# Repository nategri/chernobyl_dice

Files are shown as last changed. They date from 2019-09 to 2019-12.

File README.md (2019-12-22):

# Chernobyl Dice


<p align="center"><i>In this clip the Chernobyl Dice set to continuously generate numbers in the range [1,26]. You
can check out a longer YouTube clip showing various modes of here: https://youtu.be/8uue9Aae9ss</i></p>

## Introduction

#### Description

The Chernobyl Dice is a quantum random number generator [0] that uses nuclear decays from a weakly radioactive sample
as a source of entropy. It consists of four primary components:

* An Arduino Nano microcontroller
* A Geiger counter
* Six uranium glass marbles
* Nixie tube display

Geiger counter events ("clicks") are converted into random bits using the following algorithm:

1. In a ring buffer, for each millisecond record either a 0 or a 1, depending on whether or not a Geiger event occurred
2. Perform an initial de-bias of this 0-dominated stream using von Neumann's method [0]
3. Further de-bias by XOR-ing bits generated in the previous step with the mod2 of elapsed 4 microsecond intervals since
since the device was powered on

The uranium glass sample is illuminated by an array of ultraviolet LEDs at each Geiger event, which makes them
fluoresce bright green. This has nothing to do with the radioactivity of the sample, but it does, however, *look
really cool*.

#### Operation

The device has three modes of operations, which can be selected via the rotary switch:

*Clock Mode*

Displays the current time, with the Geiger board unpowered. The time can be set by flipping the toggle switches on and off
(the '16' toggle increments the hour, the '8' toggle increments 10 minutes, the '4' toggle increments 1 minute, and the
'1' toggle resets the seconds).

*Streaming Mode*

Repeatedly generates random numbers of a size specified by the toggles (or random bytes from 0-255 if no toggles are set). Numbers
generated in this mode are transmitted over serial via USB. This mode also has a "turbo" setting to facilitate statistical testing,
which can be enabled by holding down the pushbutton. When "turbo" is enabled bit generation will be indicated by LEDs in the
display, and the Geiger "clicks" will be silent.

*Dice Mode*

In dice mode random number generation is initiated via the pushbutton, and the size of the random number to be generated is set
by the sum of the toggled switches (no switches are set the device will generate random byte in the range 0-255). Press
once to generate the number, and once again to clear the display. The size of the number to be generated is displayed in
blinking digits.

## Statistical Performance

Further testing is required to confirm the consistency of results, but currently the Chernobyl Dice is capable of generating a
1.5+ megabit file that passes [a Python implementation](https://github.com/dj-on-github/sp800_22_tests) of the NIST statistical
test suite [1]. This means the Chernolbyl Dice is likely a *very* fair dice.

```
SUMMARY
-------
monobit_test                             0.279698915238     PASS
frequency_within_block_test              0.404035783453     PASS
runs_test                                0.0688862287393    PASS
longest_run_ones_in_a_block_test         0.959135200804     PASS
binary_matrix_rank_test                  0.532456847429     PASS
dft_test                                 0.000155432528185  FAIL
non_overlapping_template_matching_test   0.999998184707     PASS
overlapping_template_matching_test       0.55898054206      PASS
maurers_universal_test                   0.224223569722     PASS
linear_complexity_test                   0.672504584189     PASS
serial_test                              0.424389760139     PASS
approximate_entropy_test                 0.425255814114     PASS
cumulative_sums_test                     0.348500456103     PASS
random_excursion_test                    0.0753308212732    PASS
random_excursion_variant_test            0.207160448911     PASS
```

```
SUMMARY
-------
monobit_test                             0.105735760191     PASS
frequency_within_block_test              0.436487225319     PASS
runs_test                                0.648059641506     PASS
longest_run_ones_in_a_block_test         0.184787158208     PASS
binary_matrix_rank_test                  0.310400523277     PASS
dft_test                                 0.156504142574     PASS
non_overlapping_template_matching_test   1.00000015958      PASS
overlapping_template_matching_test       0.629208901365     PASS
maurers_universal_test                   0.938296605093     PASS
linear_complexity_test                   0.0880093291441    PASS
serial_test                              0.131826155057     PASS
approximate_entropy_test                 0.137234909215     PASS
cumulative_sums_test                     0.112328349057     PASS
random_excursion_test                    0.17207234069      PASS
random_excursion_variant_test            0.299605480729     PASS
```
<p align="center"><i>Statistical test suite results for two 212667 byte random binary sequences ('rand.binary.1' and 'rand.binary.2')
generated by device. EXPERTS NOTE: The last two tests of the first sequence generate the message: 'J too small
(J=181 < 500) for result to be reliable' so these tests may be ignored for that dataset.</i></p>

The directory `statistical_testing` contains some utilities for assessing and gathering data from the device, including sample
random binary data files, `rand.binary.1` and `rand.binary.2`.

## CAD Drawing

A Fusion 360 CAD drawing of the device can be viewed and downloaded at this URL:

https://a360.co/2OeFT1n

Thanks to the following GrabCAD users for their models:
* [Alex](https://grabcad.com/alex-160) (Nixie tube)
* [Mike Smith](https://grabcad.com/mike.smith-208) (Arduino Nano)
* [Dragos Ionescu](https://grabcad.com/dragos.ionescu-2) (Various pin headers)

## Overview and Parts List

*WARNING: These instructions and resources are not polished and are somewhat untested. This is a project for advanced makers, and
you should fully expect to have a bit of an adventure while building your own Chernobyl Dice! That said: Shoot me a message if
you run into trouble, and I'll try to help you out and improve the instructions as well.*

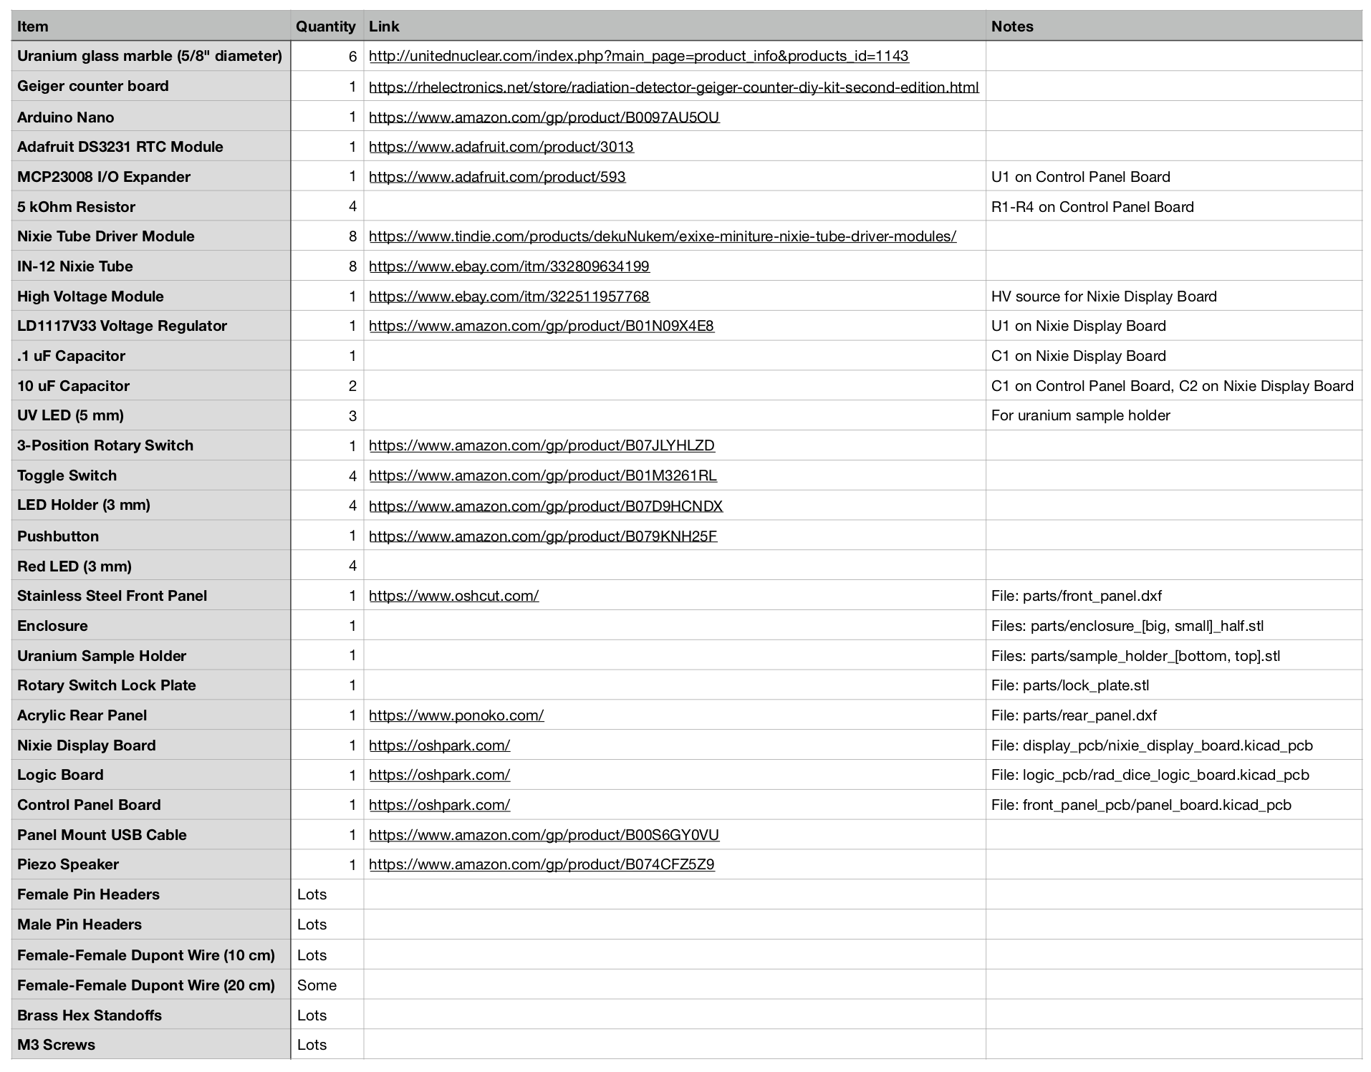
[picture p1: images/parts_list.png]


Here's a rough outline of the steps required for assembly:

1. Print or fabricate the following custom parts from files in the GitHub repository
    * Enclosure (using 3D printer or 3D printing service)
    * Logic, Nixie Display, and Control Panel Custom PCBs (using a board fabrication service such as OSHPark)
    * Stainless steel front panel (using a service such as OSHCut)
    * Acrylic back panel (using a service such as Sculpeo)
2. Order other components (see URLs in the parts list)
3. Embed brass standoffs into enclosure (this is how front and back panels and custom PCBs will be mounted)
    * TIPS
      * A single drop of cyanocrylate (superglue) should be placed in the standoff holes in the enclosure before they are pressed
        in (the tip of a Phillips head screw driver works well for this task)
      * If the tops some holes came out of the printer a bit distorted then they can be widened easily by twisting a largish
        Phillips head screwdriver in them until the top of the hole is wide enough.

4. Assemble custom PCBs and 'exixe' nixie tube driver boards using build photos as a guide
    * TIPS
      * The female headers on the Nixie Display Board for the nixie tube driver PCBs can be assembled using only four long female
        header strips (e.g. there's no need to separately attach sixteen 7-pin female headers---see photos)
      * The "CS" 8-pin male header is a currently a tight fit, so you will probably need to use needle noise pliers to push the pins
        through the board
      * For the control panel PCB you can temporarily mount the toggle switches in the front panel and then press the PCB on top of
        the back of the switches to ensure good alignment---you can then pull the whole board-and-toggle assembly off of the front
        panel to solder it, or even solder it in place and then pull it off
      * The file 'nixie_holder.stl' is a provided as a useful place to rest the nixie tube while soldering them to the 'exixe' driver
        boards
5. Attach the acrylic back panel and panel mount USB cable to the rear of the enclosure
6. Mount custom PCBs inside enclosure and perform wiring (see wiring schematic and build photos)
7. Partially dis-assemble rotary switch to attach it to the "lock plate" (lock_plate.stl)
8. Perform any necessary finishing to the stainless steel front panel
    * TIPS
      * Some mounting holes for toggles and switches may need to be widened (use a round file for this)
      * Surface finish of a laser cut part can be improved by sanding *with the grain* using ~300 grit sandpaper (test on the back
        side first)
9. Mount toggle-and-PCB assembly, LED-with-holder assemblies, rotary-switch-and-lock-plate assembly, and pushbutton on front panel
    * TIP
      * While attaching the LED to the holder, apply a drop of cyanocrylate (superglue) to prevent the LED from falling out of the
        front of the holder
10. Perform wiring of the control panel (see wiring schematic and build photos)
11. Fit the eight nixie display driver boards into the female headers of the Nixie Display Board
12. Wire the Control Panel to the Logic Board
13. Mount the front panel to the enclosure, taking care to insure that the hole in the rotary switch lock plate lines up with the
    upper-left standoff on the front of the radioactive sample holder

**Standoff Size Guide**

| Location | Standoff Length | Type |
| --- | --- | --- |
| Rear of enclosure | 10 mm | Female-Female |
| Front of enclosure | 10 mm | Female-Female |
| Nixie Display Board mount | 40 mm | Female-Female |
| Logic Board mount | 20 mm | Female-Female|
| Logic Board-to-Geiger Board | 30 mm | Male-Female |
| Geiger Board-to-Bottom of Uranium Sample Box | 15 mm | Male-Female |
| Bottom of Uranium Sample Box-to-Top of Uranium Sample Box | 6 mm | Male-Female |
| Top of Uranium Sample Box-to-Front Panel | 6 mm | Male-Female |

NOTE: For large internal standoff distances (e.g. the Nixie Display mount) two standoffs can be stacked to achieve
the desired distance.

## Wiring Diagram

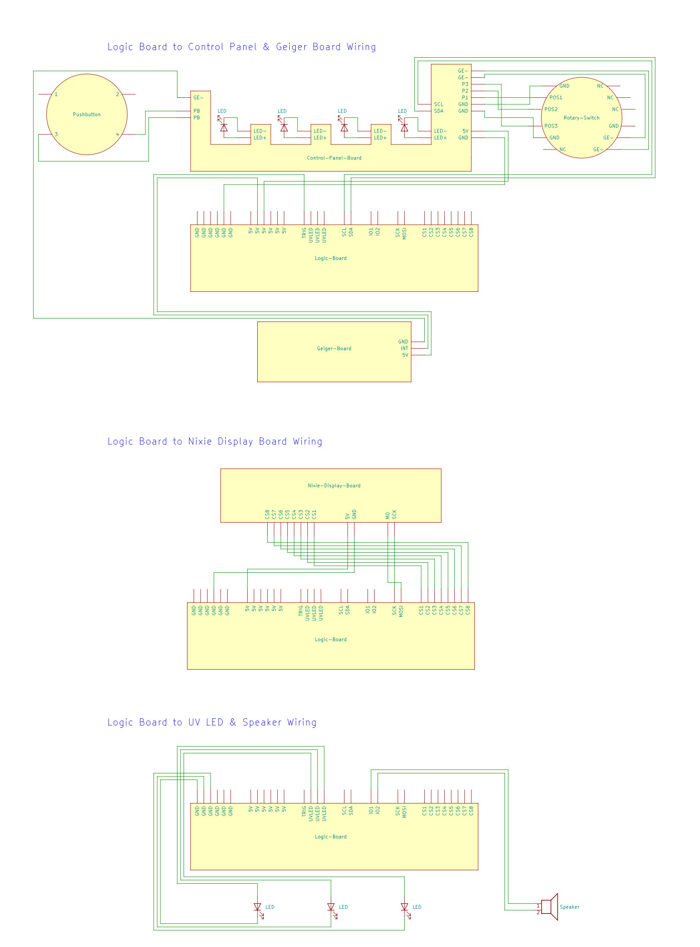
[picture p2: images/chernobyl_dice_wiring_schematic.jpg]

<p align="center"><i>How connect the internal wiring of the Chernobyl Dice.</i></p>

## Build Photos

**Enclosure with Standoffs Inserted**
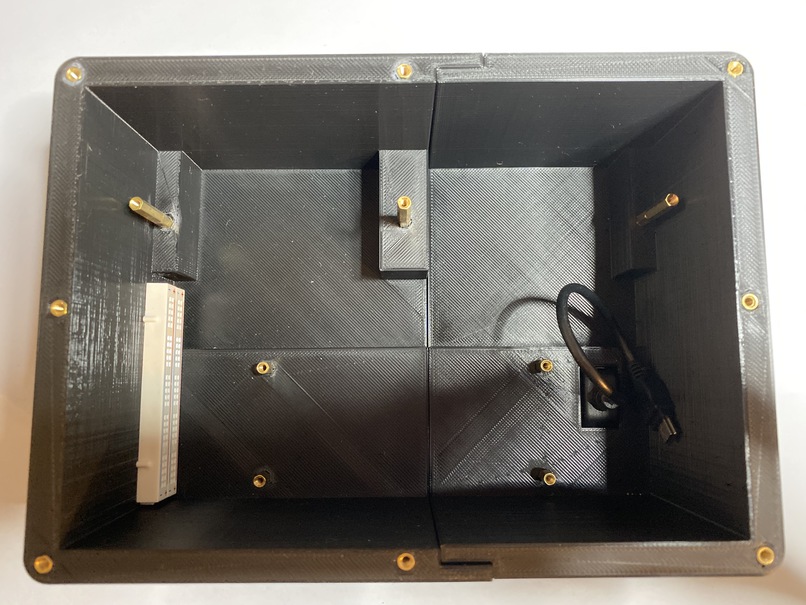
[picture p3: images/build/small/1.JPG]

<p align="center"><i>
You can ignore the white breadboards on the left of the enclosure. These assisted in an earlier iteration of the
project and are not needed for assembly.
<a href="https://raw.githubusercontent.com/nategri/chernobyl_dice/master/images/build/large/1.JPG">Click here</a>
for larger photo.
</i></p>

<br><br><br>

**Logic Board Mounted**
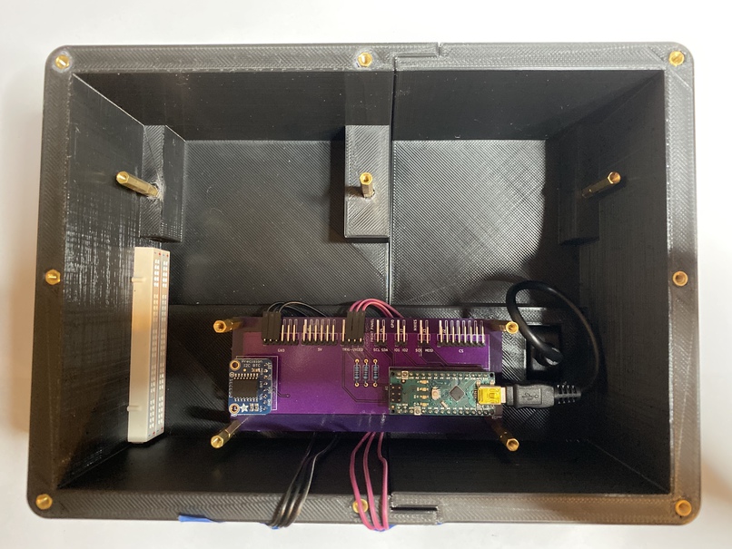
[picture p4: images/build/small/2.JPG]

<p align="center"><i>
Note the wires for UV LED array are run beneath the logic board.
<a href="https://raw.githubusercontent.com/nategri/chernobyl_dice/master/images/build/large/2.JPG">Click here</a>
for larger photo.
</i></p>

<br><br><br>

**Nixie Display Board Wiring**
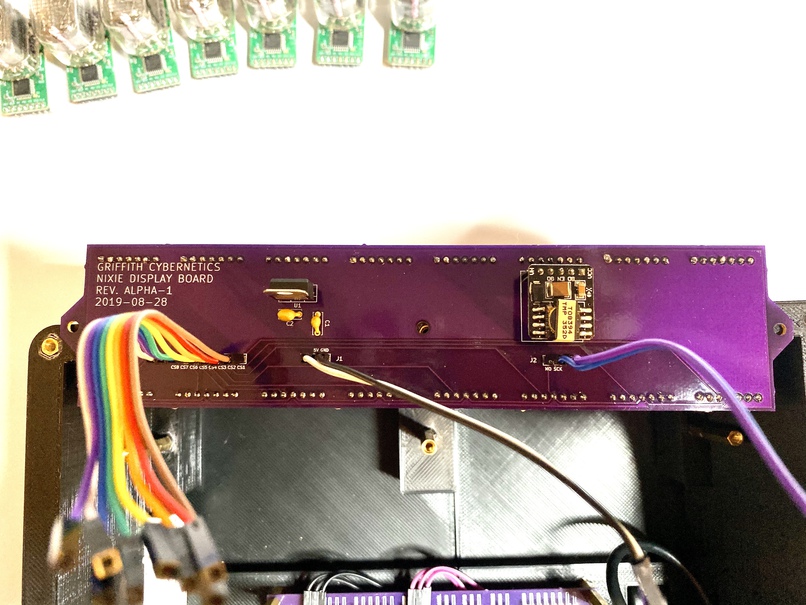
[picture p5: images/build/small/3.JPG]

<p align="center"><i>
<a href="https://raw.githubusercontent.com/nategri/chernobyl_dice/master/images/build/large/3.JPG">Click here</a>
for larger photo.
</i></p>

<br><br><br>

**Nixie Display Board Mounted and Logic Board Wiring**
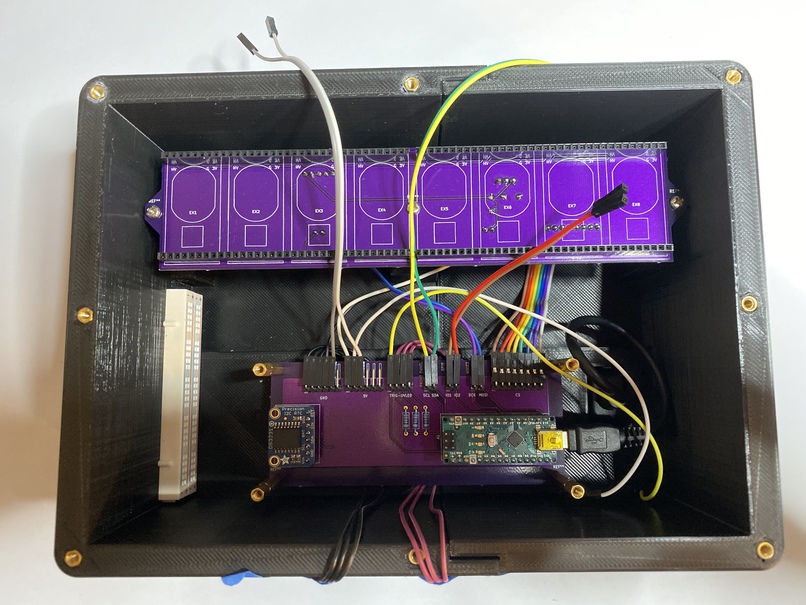
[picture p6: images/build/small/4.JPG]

<p align="center"><i>
<a href="https://raw.githubusercontent.com/nategri/chernobyl_dice/master/images/build/large/4.JPG">Click here</a>
for larger photo.
</i></p>

<br><br><br>

**Geiger Board Mounted**
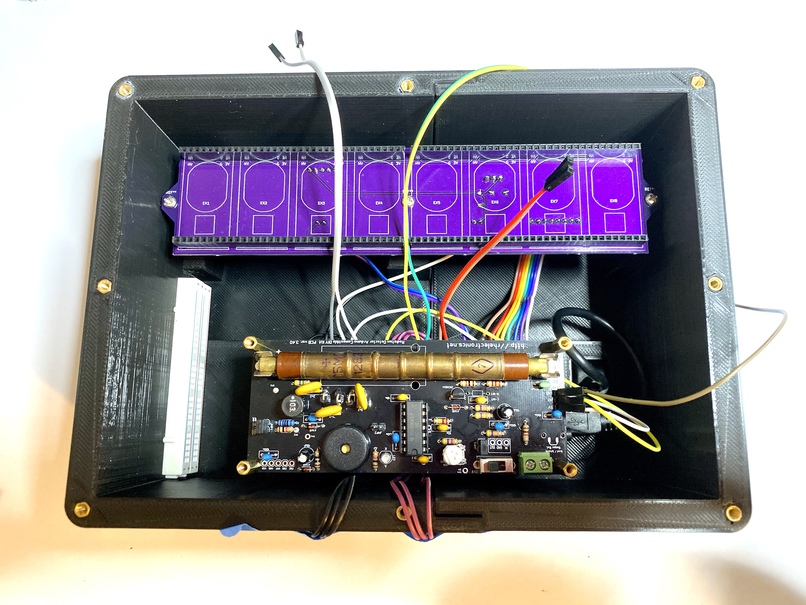
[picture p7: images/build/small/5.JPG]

<p align="center"><i>
NOTE: You must pull the JMP2 jumper near the center of the Geiger board (this turns off the built-in speaker of the
board---we want these clicks to be optional and controlled by firmware instead).
<a href="https://raw.githubusercontent.com/nategri/chernobyl_dice/master/images/build/large/5.JPG">Click here</a>
for larger photo.
</i></p>

<br><br><br>

**Uranium Sample Holder Lower Half Detail**
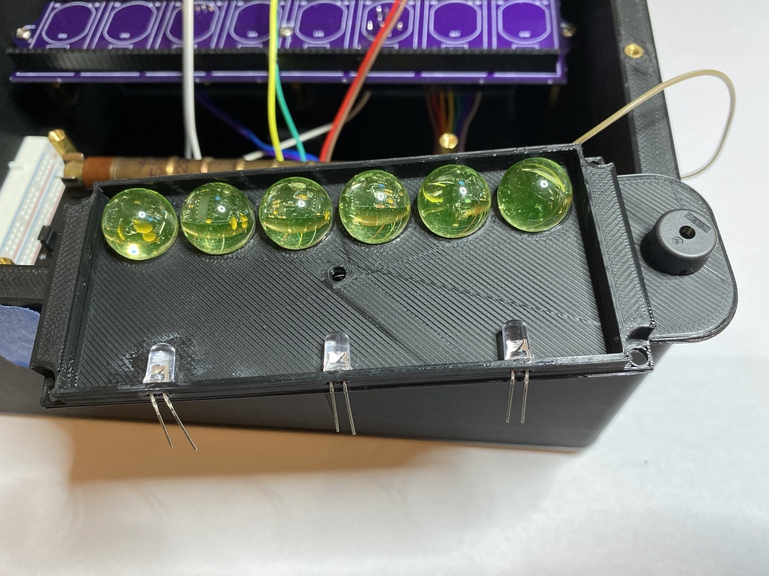
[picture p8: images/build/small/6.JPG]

<p align="center"><i>
UV LEDs and piezo speaker are glued mounted into place using cyanocrylate (superglue) adhesive. Uranium glass
marbles will be held in place mechanically when the top half is mounted.
<a href="https://raw.githubusercontent.com/nategri/chernobyl_dice/master/images/build/large/6.JPG">Click here</a>
for larger photo.
</i></p>

<br><br><br>

**Uranium Sample Holder Lower Half Mounted**
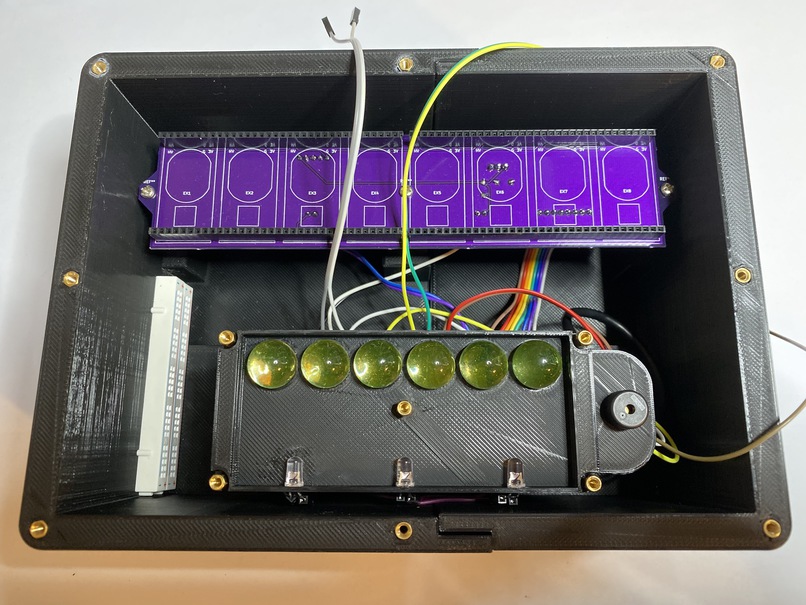
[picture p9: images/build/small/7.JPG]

<p align="center"><i>
The middle standoff is attached on the underside with a nut.
<a href="https://raw.githubusercontent.com/nategri/chernobyl_dice/master/images/build/large/7.JPG">Click here</a>
for larger photo.
</i></p>

<br><br><br>

**Uranium Sample Holder Top Half Mounted**
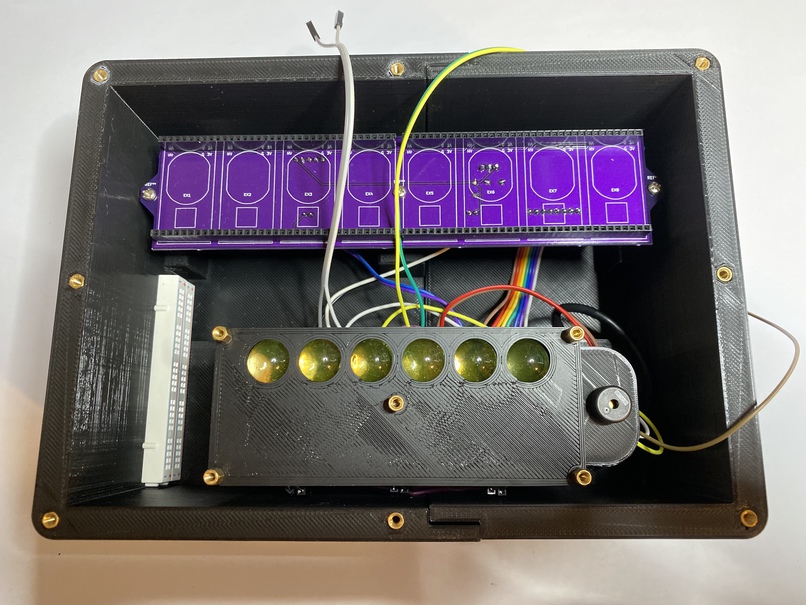
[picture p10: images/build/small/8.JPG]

<p align="center"><i>
<a href="https://raw.githubusercontent.com/nategri/chernobyl_dice/master/images/build/large/8.JPG">Click here</a>
for larger photo.
</i></p>

<br><br><br>

**Control Panel Board Wired**
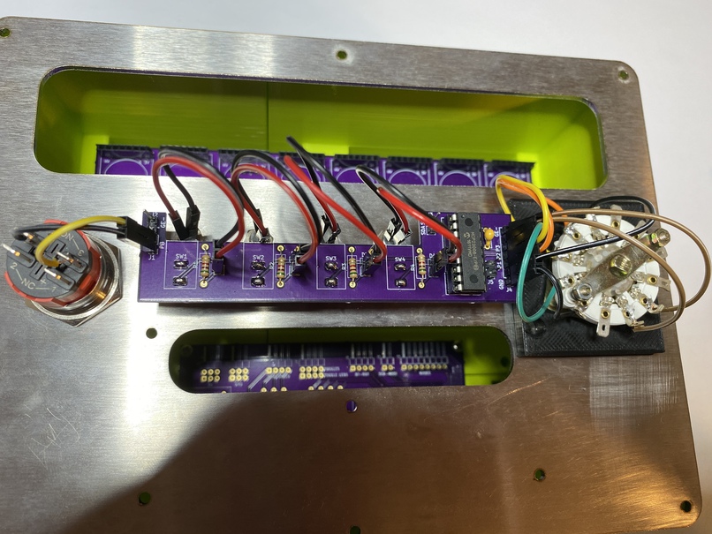
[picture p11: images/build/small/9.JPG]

<p align="center"><i>
<a href="https://raw.githubusercontent.com/nategri/chernobyl_dice/master/images/build/large/9.JPG">Click here</a>
for larger photo.
</i></p>

<br><br><br>

**Control Panel Board Wiring Detail**
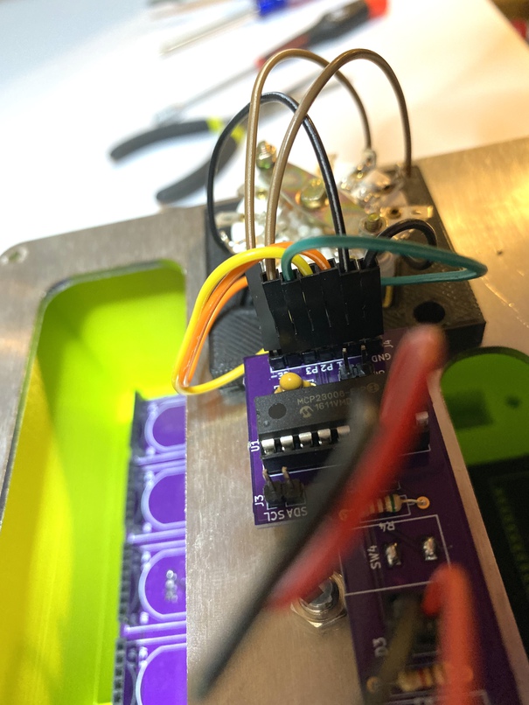
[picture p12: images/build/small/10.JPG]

<p align="center"><i>
<a href="https://raw.githubusercontent.com/nategri/chernobyl_dice/master/images/build/large/10.JPG">Click here</a>
for larger photo.
</i></p>

## Acknowledgements

Many thanks to Emily Velasco ([@MLE_Online](https://twitter.com/MLE_Online)) for advice on stainless steel surface sanding,
and for generally being enthusiastic as heck about this project.

## References

[0] "Quantum Random Number Generators." M. Herrero-Collantes and J. C. Garcia-Escartin.
https://arxiv.org/abs/1604.03304

[1] "A Statistical Test Suite for Random and Pseudorandom Number Generators for Cryptographic Applications."
https://csrc.nist.gov/publications/detail/sp/800-22/rev-1a/final

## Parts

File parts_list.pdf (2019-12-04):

Item | Quantity | Link | Notes
Uranium glass marble (5/8" diameter) | 6 | http://unitednuclear.com/index.php?main_page=product_info&products_id=1143
Geiger counter board | 1 | https://rhelectronics.net/store/radiation-detector-geiger-counter-diy-kit-second-edition.html
Arduino Nano | 1 | https://www.amazon.com/gp/product/B0097AU5OU
Adafruit DS3231 RTC Module | 1 | https://www.adafruit.com/product/3013
MCP23008 I/O Expander | 1 | https://www.adafruit.com/product/593 | U1 on Control Panel Board
5 kOhm Resistor | 4 | | R1-R4 on Control Panel Board
Nixie Tube Driver Module | 8 | https://www.tindie.com/products/dekuNukem/exixe-miniture-nixie-tube-driver-modules/
IN-12 Nixie Tube | 8 | https://www.ebay.com/itm/332809634199
High Voltage Module | 1 | https://www.ebay.com/itm/322511957768 | HV source for Nixie Display Board
LD1117V33 Voltage Regulator | 1 | https://www.amazon.com/gp/product/B01N09X4E8 | U1 on Nixie Display Board
.1 uF Capacitor | 1 | | C1 on Nixie Display Board
10 uF Capacitor | 2 | | C1 on Control Panel Board, C2 on Nixie Display Board
UV LED (5 mm) | 3 | | For uranium sample holder
3-Position Rotary Switch | 1 | https://www.amazon.com/gp/product/B07JLYHLZD
Toggle Switch | 4 | https://www.amazon.com/gp/product/B01M3261RL
LED Holder (3 mm) | 4 | https://www.amazon.com/gp/product/B07D9HCNDX
Pushbutton | 1 | https://www.amazon.com/gp/product/B079KNH25F
Red LED (3 mm) | 4
Stainless Steel Front Panel | 1 | https://www.oshcut.com/ | File: parts/front_panel.dxf
Enclosure | 1 | | Files: parts/enclosure_[big, small]_half.stl
Uranium Sample Holder | 1 | | Files: parts/sample_holder_[bottom, top].stl
Rotary Switch Lock Plate | 1 | | File: parts/lock_plate.stl
Acrylic Rear Panel | 1 | https://www.ponoko.com/ | File: parts/rear_panel.dxf
Nixie Display Board | 1 | https://oshpark.com/ | File: display_pcb/nixie_display_board.kicad_pcb
Logic Board | 1 | https://oshpark.com/ | File: logic_pcb/rad_dice_logic_board.kicad_pcb
Control Panel Board | 1 | https://oshpark.com/ | File: front_panel_pcb/panel_board.kicad_pcb
Panel Mount USB Cable | 1 | https://www.amazon.com/gp/product/B00S6GY0VU
Piezo Speaker | 1 | https://www.amazon.com/gp/product/B074CFZ5Z9
Female Pin Headers | Lots
Male Pin Headers | Lots
Female-Female Dupont Wire (10 cm) | Lots
Female-Female Dupont Wire (20 cm) | Some
Brass Hex Standoffs | Lots
M3 Screws | Lots

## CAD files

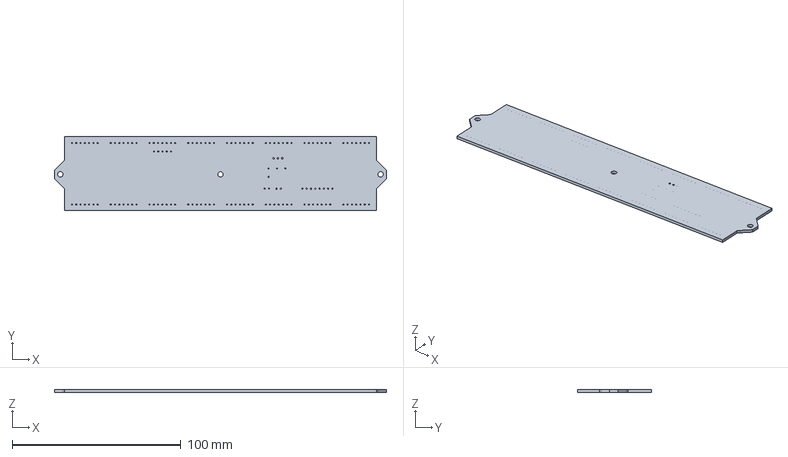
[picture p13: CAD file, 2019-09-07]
display_pcb/nixie_display_board.step
197.0 x 44.0 x 1.60 mm

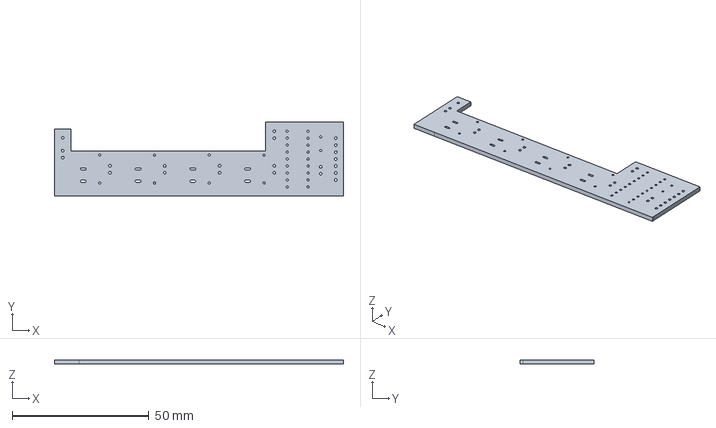
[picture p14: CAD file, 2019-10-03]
front_panel_pcb/panel_board.step
105.5 x 27.0 x 1.60 mm

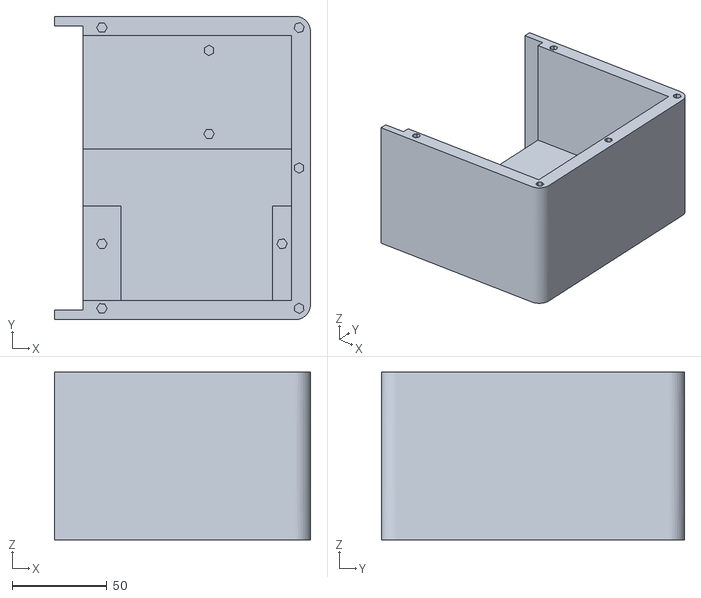
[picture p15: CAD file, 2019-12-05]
parts/enclosure_big_half.stl
135.0 x 160.0 x 88.4

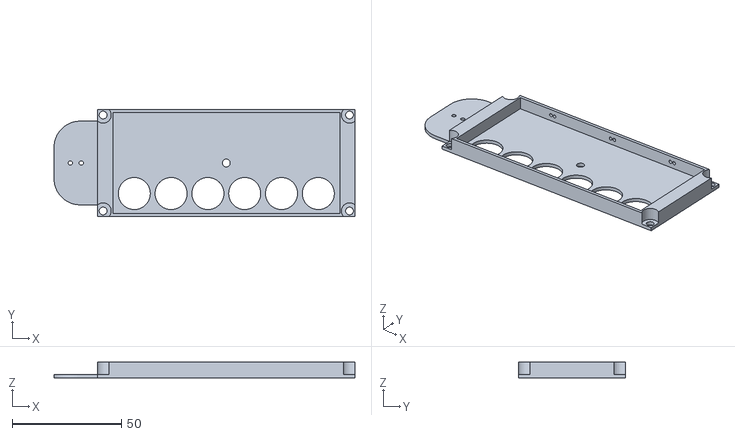
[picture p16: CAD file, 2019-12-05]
parts/sample_holder_bottom.stl
138.0 x 49.0 x 7.30

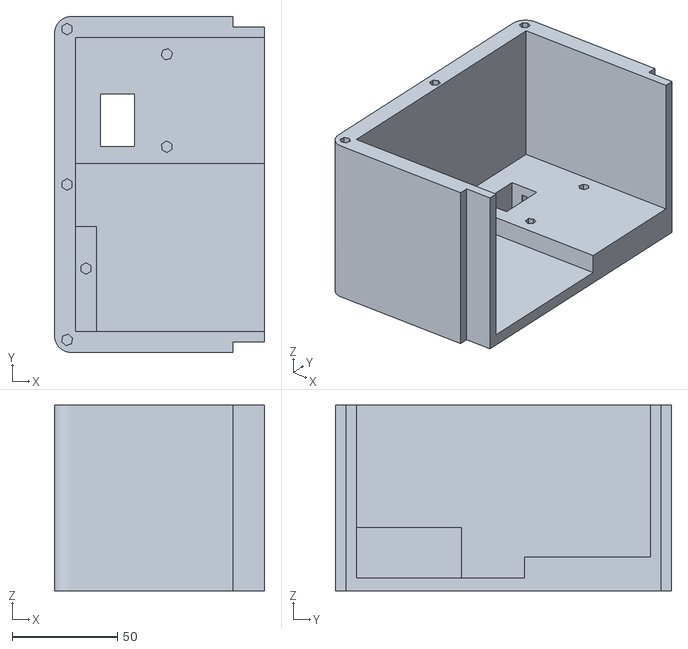
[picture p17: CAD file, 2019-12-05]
parts/enclosure_small_half.stl
100.0 x 160.0 x 88.4

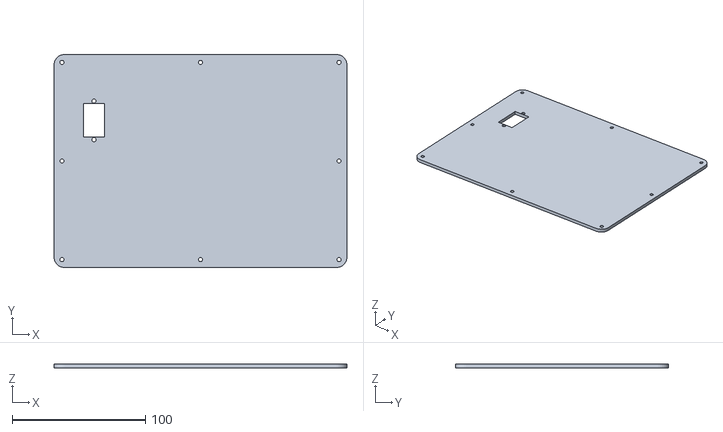
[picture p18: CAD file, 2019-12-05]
parts/rear_panel.stl
220.0 x 160.0 x 3.00

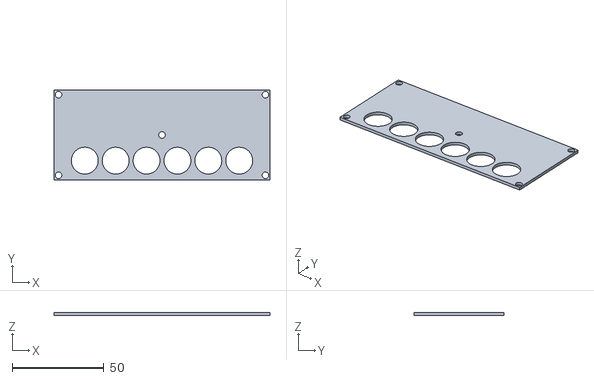
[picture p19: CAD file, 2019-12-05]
parts/sample_holder_top.stl
118.0 x 49.0 x 1.60

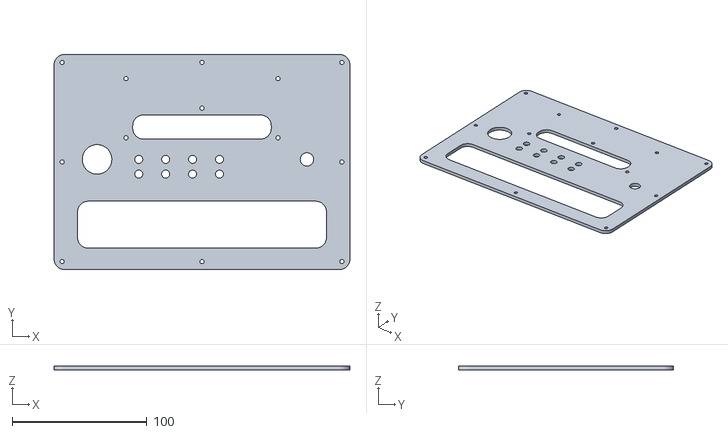
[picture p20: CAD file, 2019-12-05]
parts/front_panel.stl
220.0 x 160.0 x 3.00

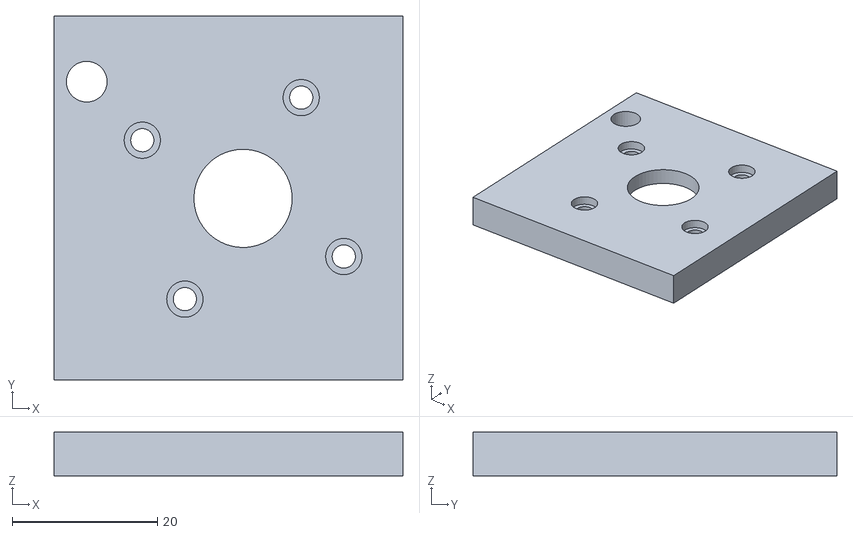
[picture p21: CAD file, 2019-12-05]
parts/lock_plate.stl
48.0 x 50.0 x 6.00

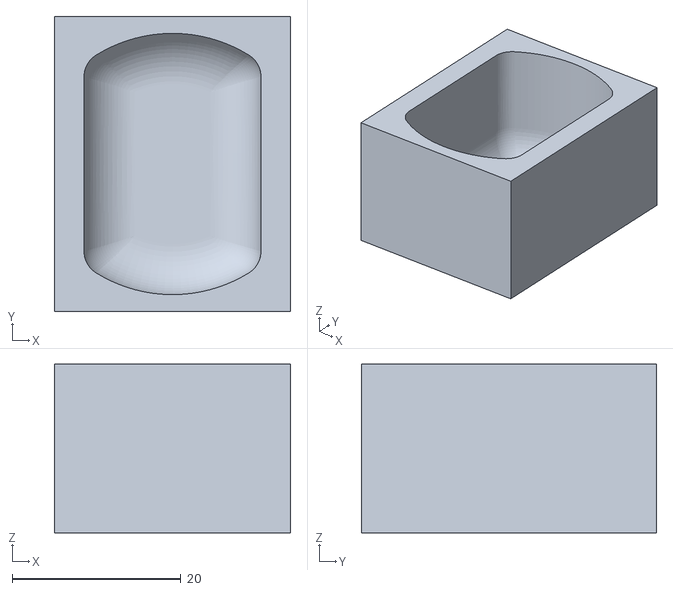
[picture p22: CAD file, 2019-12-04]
parts/nixie_holder.stl
28.0 x 35.0 x 20.0

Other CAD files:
parts/front_panel.dxf
parts/rear_panel.dxf

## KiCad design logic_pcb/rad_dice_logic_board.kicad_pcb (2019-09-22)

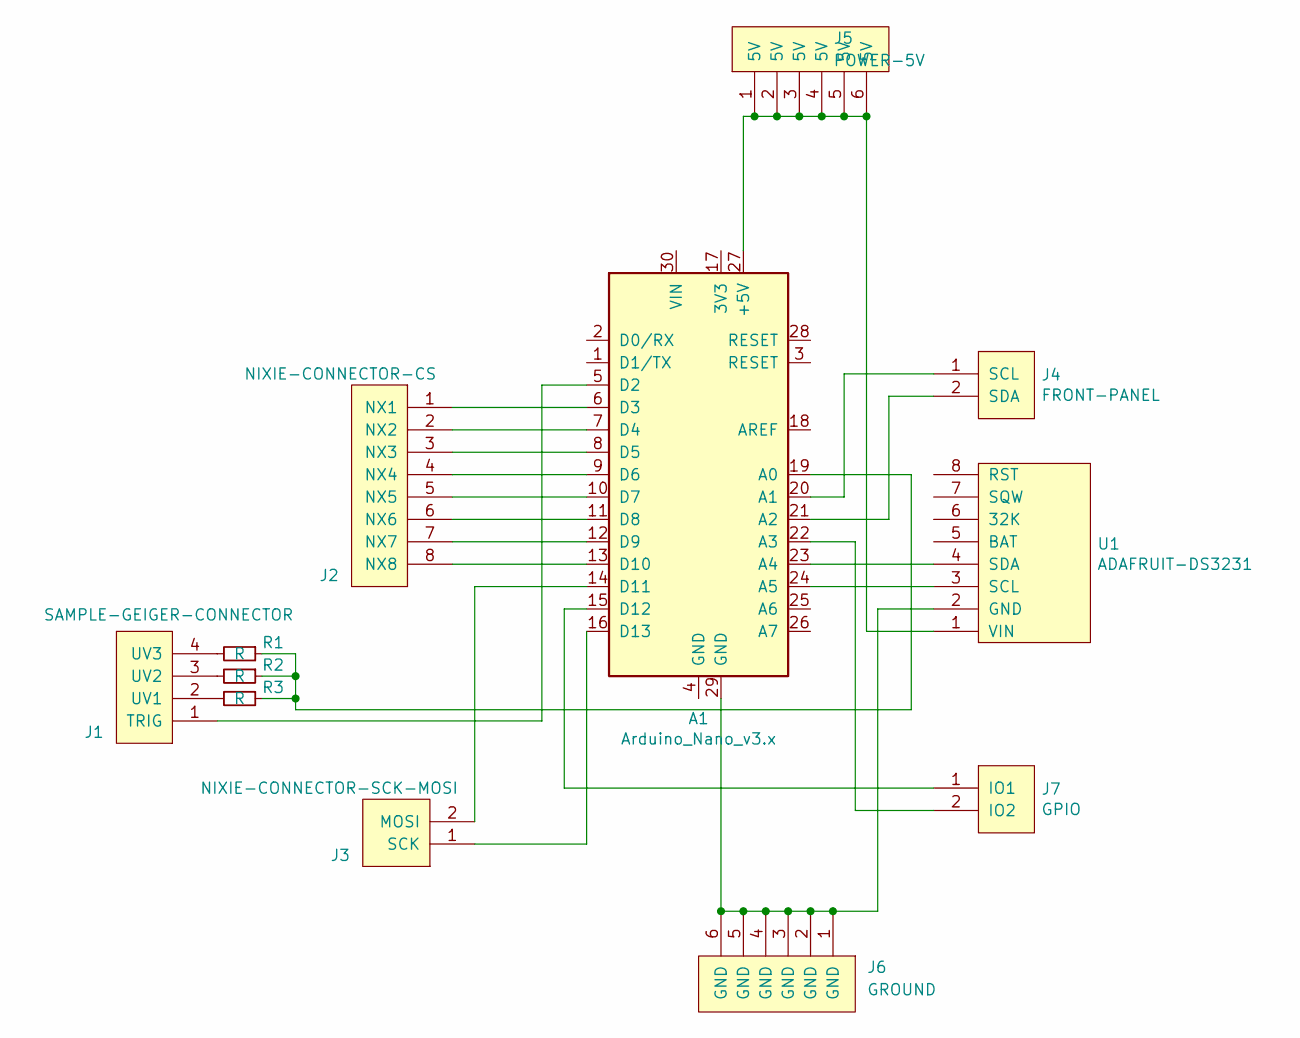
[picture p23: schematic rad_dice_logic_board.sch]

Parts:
A1: Arduino_Nano_v3.x; Arduino_Nano
J1: SAMPLE-GEIGER-CONNECTOR; Pin_Header_Angled_1x04_Pitch2.54mm
J2: NIXIE-CONNECTOR-CS; Pin_Header_Angled_1x08_Pitch2.54mm
J3: NIXIE-CONNECTOR-SCK-MOSI; Pin_Header_Angled_1x02_Pitch2.54mm
J4: FRONT-PANEL; Pin_Header_Angled_1x02_Pitch2.54mm
J5: POWER-5V; Pin_Header_Angled_1x06_Pitch2.54mm
J6: GROUND; Pin_Header_Angled_1x06_Pitch2.54mm
J7: GPIO; Pin_Header_Angled_1x02_Pitch2.54mm
R1, R2, R3: R; R_Axial_DIN0207_L6.3mm_D2.5mm_P10.16mm_Horizontal
U1: ADAFRUIT-DS3231

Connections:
unnamed: A1.5 (D2), J1.1 (TRIG)
unnamed: A1.6 (D3), J2.1 (NX1)
unnamed: A1.7 (D4), J2.2 (NX2)
unnamed: A1.8 (D5), J2.3 (NX3)
unnamed: A1.9 (D6), J2.4 (NX4)
unnamed: A1.10 (D7), J2.5 (NX5)
unnamed: A1.11 (D8), J2.6 (NX6)
unnamed: A1.12 (D9), J2.7 (NX7)
unnamed: A1.13 (D10), J2.8 (NX8)
unnamed: A1.14 (D11), J3.2 (MOSI)
unnamed: A1.15 (D12), J7.1 (IO1)
unnamed: A1.16 (D13), J3.1 (SCK)
unnamed: A1.19 (A0), R1.1, R2.1, R3.1
unnamed: A1.20 (A1), J4.1 (SCL)
unnamed: A1.21 (A2), J4.2 (SDA)
unnamed: A1.22 (A3), J7.2 (IO2)
unnamed: A1.23 (A4), U1.4 (SDA)
unnamed: A1.24 (A5), U1.3 (SCL)
unnamed: A1.27 (+5V), J5.1, J5.2, J5.3, J5.4, J5.5, J5.6, U1.1 (VIN)
unnamed: A1.29 (GND), J6.1, J6.2, J6.3, J6.4, J6.5, J6.6, U1.2 (GND)
unnamed: J1.2 (UV1), R3.2
unnamed: J1.3 (UV2), R2.2
unnamed: J1.4 (UV3), R1.2

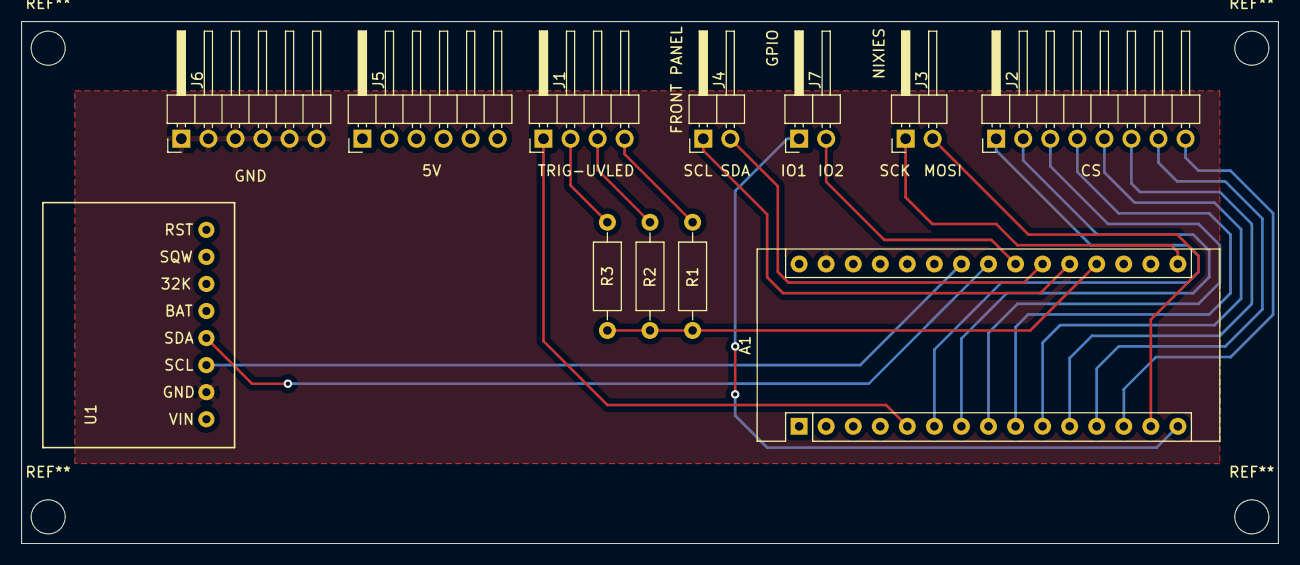
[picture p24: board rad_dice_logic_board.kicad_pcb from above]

Board: 2 copper layers, 118.0 x 49.0 mm, 12 parts (0 on the bottom side), 23 nets.

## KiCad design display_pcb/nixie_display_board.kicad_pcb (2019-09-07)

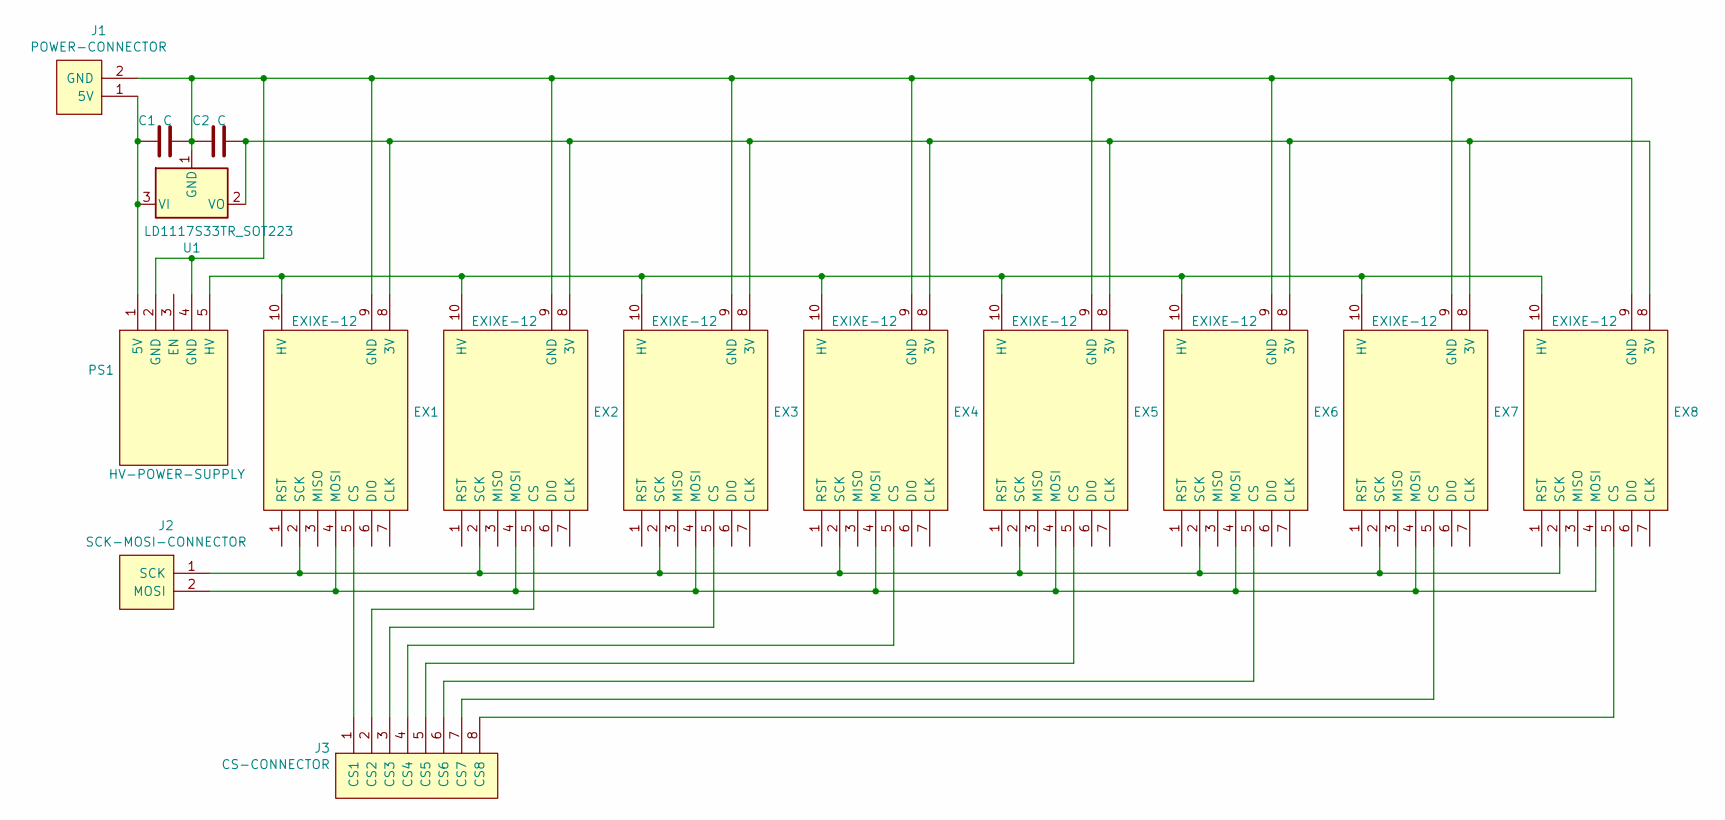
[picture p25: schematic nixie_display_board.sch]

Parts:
C1, C2: C; C_Disc_D6.0mm_W2.5mm_P5.00mm
EX1, EX2, EX3, EX4, EX5, EX6, EX7, EX8: EXIXE-12; exixe-12-board
J1: POWER-CONNECTOR; power-connector
J2: SCK-MOSI-CONNECTOR; sck-mosi-connector
J3: CS-CONNECTOR; cs-connector
PS1: HV-POWER-SUPPLY; hv-power-supply
U1: LD1117S33TR_SOT223; TO-220-3_Vertical

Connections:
unnamed: C1.1, J1.1 (5V), PS1.1 (5V), U1.3 (VI)
unnamed: C1.2, C2.1, EX1.9 (GND), EX2.9 (GND), EX3.9 (GND), EX4.9 (GND), EX5.9 (GND), EX6.9 (GND), EX7.9 (GND), EX8.9 (GND), J1.2 (GND), PS1.2 (GND), PS1.4 (GND), U1.1 (GND)
unnamed: C2.2, EX1.8 (3V), EX2.8 (3V), EX3.8 (3V), EX4.8 (3V), EX5.8 (3V), EX6.8 (3V), EX7.8 (3V), EX8.8 (3V), U1.2 (VO)
unnamed: EX1.2 (SCK), EX2.2 (SCK), EX3.2 (SCK), EX4.2 (SCK), EX5.2 (SCK), EX6.2 (SCK), EX7.2 (SCK), EX8.2 (SCK), J2.1 (SCK)
unnamed: EX1.4 (MOSI), EX2.4 (MOSI), EX3.4 (MOSI), EX4.4 (MOSI), EX5.4 (MOSI), EX6.4 (MOSI), EX7.4 (MOSI), EX8.4 (MOSI), J2.2 (MOSI)
unnamed: EX1.5 (CS), J3.1 (CS1)
unnamed: EX1.10 (HV), EX2.10 (HV), EX3.10 (HV), EX4.10 (HV), EX5.10 (HV), EX6.10 (HV), EX7.10 (HV), EX8.10 (HV), PS1.5 (HV)
unnamed: EX2.5 (CS), J3.2 (CS2)
unnamed: EX3.5 (CS), J3.3 (CS3)
unnamed: EX4.5 (CS), J3.4 (CS4)
unnamed: EX5.5 (CS), J3.5 (CS5)
unnamed: EX6.5 (CS), J3.6 (CS6)
unnamed: EX7.5 (CS), J3.7 (CS7)
unnamed: EX8.5 (CS), J3.8 (CS8)

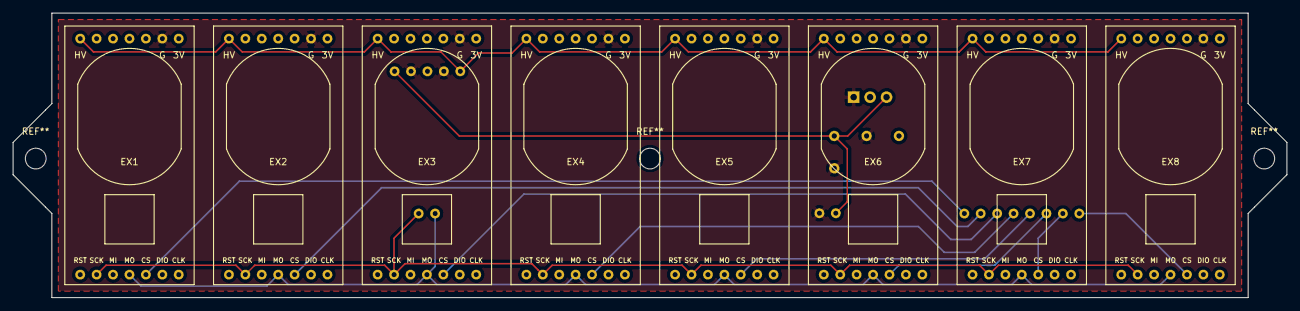
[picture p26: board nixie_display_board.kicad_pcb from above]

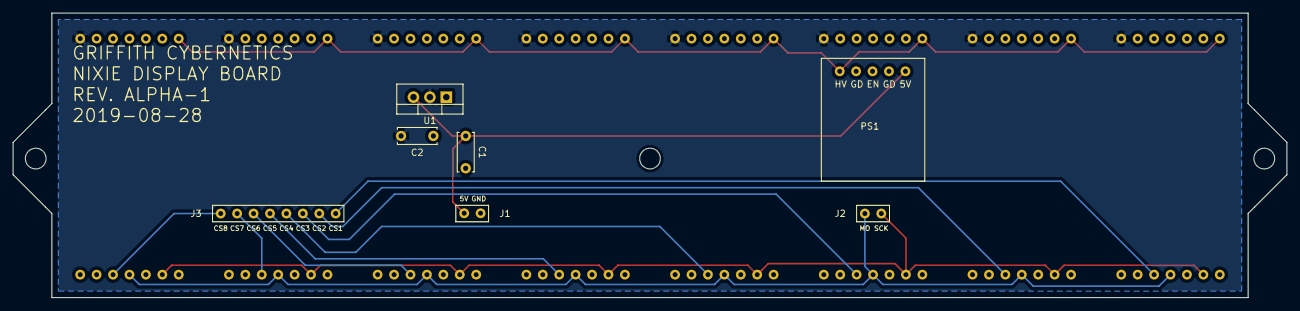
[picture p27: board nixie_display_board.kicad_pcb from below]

Board: 2 copper layers, 197.0 x 44.0 mm, 15 parts (7 on the bottom side), 14 nets.

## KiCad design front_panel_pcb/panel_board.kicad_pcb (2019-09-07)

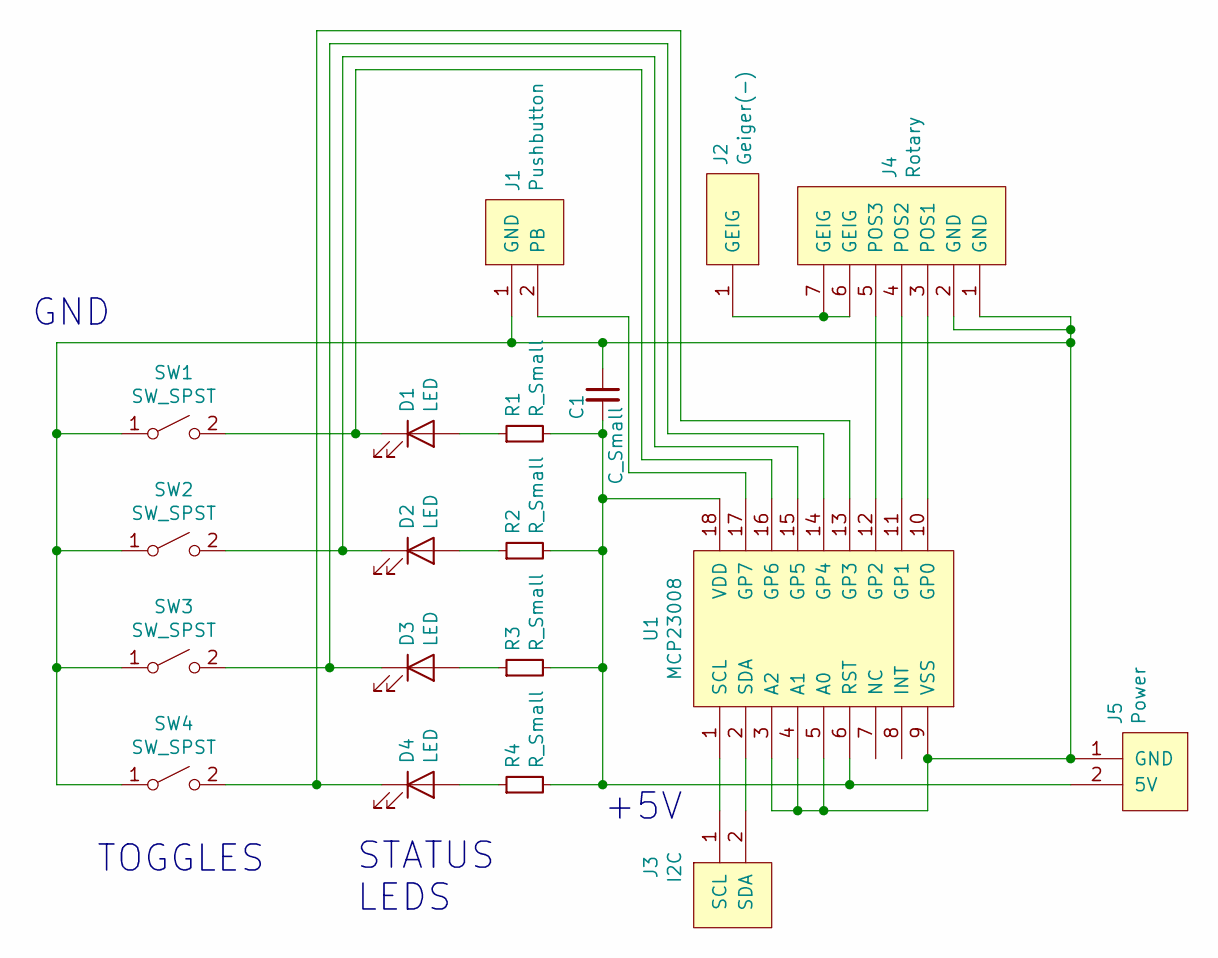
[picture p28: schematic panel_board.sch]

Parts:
C1: C_Small; C_Disc_D6.0mm_W2.5mm_P5.00mm
D1, D2, D3, D4: LED; Pin_Header_Straight_1x02_Pitch2.54mm
J1: Pushbutton; Pin_Header_Straight_1x02_Pitch2.54mm
J2: Geiger(-); Pin_Header_Straight_1x01_Pitch2.54mm
J3: I2C; Pin_Header_Straight_1x02_Pitch2.54mm
J4: Rotary; Pin_Header_Straight_1x07_Pitch2.54mm
J5: Power; Pin_Header_Straight_1x02_Pitch2.54mm
R1, R2, R3, R4: R_Small; R_Axial_DIN0207_L6.3mm_D2.5mm_P10.16mm_Horizontal
SW1, SW2, SW3, SW4: SW_SPST; ToggleSW
U1: MCP23008; DIP-18_W7.62mm_Socket

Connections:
unnamed: C1.1, J1.1 (GND), J4.1 (GND), J4.2 (GND), J5.1 (GND), SW1.1 (A), SW2.1 (A), SW3.1 (A), SW4.1 (A), U1.3 (A2), U1.4 (A1), U1.5 (A0), U1.9 (VSS)
unnamed: C1.2, J5.2 (5V), R1.2, R2.2, R3.2, R4.2, U1.6 (RST), U1.18 (VDD)
unnamed: D1.1 (K), SW1.2 (B), U1.16 (GP6)
unnamed: D1.2 (A), R1.1
unnamed: D2.1 (K), SW2.2 (B), U1.15 (GP5)
unnamed: D2.2 (A), R2.1
unnamed: D3.1 (K), SW3.2 (B), U1.14 (GP4)
unnamed: D3.2 (A), R3.1
unnamed: D4.1 (K), SW4.2 (B), U1.13 (GP3)
unnamed: D4.2 (A), R4.1
unnamed: J1.2 (PB), U1.17 (GP7)
unnamed: J2.1, J4.6 (GEIG), J4.7 (GEIG)
unnamed: J3.1 (SCL), U1.1 (SCL)
unnamed: J3.2 (SDA), U1.2 (SDA)
unnamed: J4.3 (POS1), U1.10 (GP0)
unnamed: J4.4 (POS2), U1.11 (GP1)
unnamed: J4.5 (POS3), U1.12 (GP2)

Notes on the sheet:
+5V
GND
STATUS LEDS
TOGGLES

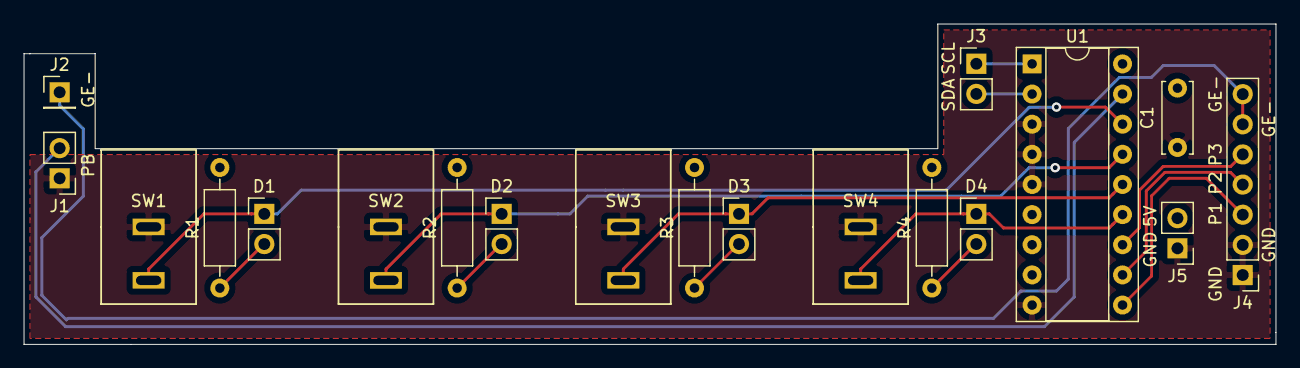
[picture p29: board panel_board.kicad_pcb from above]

Board: 2 copper layers, 105.5 x 27.0 mm, 19 parts (0 on the bottom side), 17 nets.

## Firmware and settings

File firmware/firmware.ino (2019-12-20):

#define UV_LED_PIN 14

// Address to store whether or not device is in "turbo mode"
// Increment this if it starts acting funny (WOW YOU'VE TOGGLED IT A LOT HUH)
#define EEPROM_ADDR 11

#include <EEPROM.h>

#include "RTClib.h"

#include "exixe.h"

#include "nixies.h"
#include "controlpanel.h"
#include "speaker.h"

RTC_DS3231 rtc;

volatile uint8_t didTrigger;
volatile unsigned long prevTrigTime;
volatile unsigned long trigCount;

// Ring buffer for Von Neumann algorithm based algorithm 
volatile uint8_t vnRingBuff[256];
volatile uint8_t vnRingBuffWriteHead;

// Global variables for state machine
uint8_t turboMode;
uint8_t speakerOn;
uint8_t trigLedsOn;

uint16_t toggleNum;
uint8_t prevToggleNum; // Assists in clock's time-setting logic

// Interfaces to various hardware components
Nixies* nixies;
ControlPanel* controlPanel;
Speaker* speaker;

void geigerEvent() {
  if(trigLedsOn) {
    digitalWrite(UV_LED_PIN, HIGH);
  }

  if(speakerOn) {
    speaker->clickBegin();
  }

  didTrigger = 1;
  prevTrigTime = millis();
  trigCount++;
}

ISR(TIMER0_COMPA_vect) {
  // Turn off UV LEDs if it's been more than 50 ms since last trigger
  // Also a finish a "click" on the piezo speaker if it's been 1 ms or more
  unsigned long now = millis();

  unsigned long dt = now - prevTrigTime;

  if(dt > 50) {
    digitalWrite(UV_LED_PIN, LOW);
  }

  if(dt >= 1) {
    if(speakerOn) {
      speaker->clickEnd();
    }
  }

  // Handle this 1 ms window
  if(didTrigger) {
    vnRingBuff[vnRingBuffWriteHead] = 1;
    didTrigger = 0;
  }
  else {
    vnRingBuff[vnRingBuffWriteHead] = 0;
  }

  vnRingBuffWriteHead++;
}

uint8_t getRandByte(unsigned char callingPosition) {
  
  uint8_t randByte = 0;

  uint8_t vnRingBuffReadHead = vnRingBuffWriteHead - 2;

  uint8_t currBit = 0;

  uint8_t digits[] = {-1, -1, -1, -1, -1, -1, -1, -1};
  nixies->display(digits);

  while(currBit < 8) {

    uint8_t bitContribution = 0b00000001 << currBit;
    
    while(1) {
      if(controlPanel->switch_state(callingPosition) != LOW) {
        return 0;
      }

      uint8_t diff = vnRingBuffWriteHead - vnRingBuffReadHead;
      
      if(diff >= 2) {
        // Generate a bit
        uint8_t idx = vnRingBuffReadHead;
        vnRingBuffReadHead += 2;

        if(vnRingBuff[idx] == vnRingBuff[idx+1]) {
          continue;
        }
        else if((vnRingBuff[idx] == 1) && (vnRingBuff[idx+1] == 0)) {
          randByte += bitContribution;
          uint8_t parity = (micros() / 4) % 2;
          randByte = randByte ^ (parity << currBit);
          currBit++;
          break;
        }
        else if((vnRingBuff[idx] == 0) && (vnRingBuff[idx+1] == 1)) {
          uint8_t parity = (micros() / 4) % 2;
          randByte = randByte ^ (parity << currBit);
          currBit++;
          break;
        }
      }
      
    }
    
    uint8_t newBit = (randByte & bitContribution) >> (currBit-1);

    digits[currBit-1] = newBit;

    if(!turboMode) {
      nixies->display(digits);
    }
    else {
      nixies->display_led(digits);
    }
  }

  return randByte;
}

// Read off what number is indicated in the toggles
uint8_t readToggles() {
    uint8_t toggleNum = 0;
    if(controlPanel->switch_state(TOGGLE1) == LOW) {
      toggleNum += 16;
    }
    if(controlPanel->switch_state(TOGGLE2) == LOW) {
      toggleNum += 8;
    }
    if(controlPanel->switch_state(TOGGLE3) == LOW) {
      toggleNum += 4;
    }
    if(controlPanel->switch_state(TOGGLE4) == LOW) {
      toggleNum += 2;
    }

    return toggleNum;
}

void setup() {

  // Init real time clock
  rtc.begin();
  
  // put your setup code here, to run once:
  nixies = new Nixies();
  controlPanel = new ControlPanel();
  speaker = new Speaker();

  vnRingBuffWriteHead = 0;
  prevTrigTime = 0;
  trigCount = 0;
  vnRingBuff[vnRingBuffWriteHead] = 0;

  // Settings for Timer0 interrupt
  OCR0A = 0xAF; // Count at which to insert interrupt
  TIMSK0 |= _BV(OCIE0A);

  // Init LED flash pin
  pinMode(UV_LED_PIN, OUTPUT);

  // Is device in turbo mode?
  if(EEPROM.read(EEPROM_ADDR) == 0xFF) {
    // NOTE: 0xFF is what's stored when the Arduino is factory-fresh
    turboMode = 0;
  }
  else if(EEPROM.read(EEPROM_ADDR) == 0x00) {
    turboMode = 1;
  }

  // Attach geiger counter interrupt
  pinMode(2, INPUT_PULLUP);
  attachInterrupt(0, geigerEvent, FALLING);

  // Initialize prevToggle num to max value so it doesn't trip clock-setting logic
  prevToggleNum = 30;
}

void loop() {
  // put your main code here, to run repeatedly:
  unsigned int rotPos1 = controlPanel->switch_state(ROTARYPOSITION1);
  unsigned int rotPos2 = controlPanel->switch_state(ROTARYPOSITION2);
  unsigned int rotPos3 = controlPanel->switch_state(ROTARYPOSITION3);
  toggleNum = readToggles();

  if((!rotPos2 || !rotPos3) && (trigCount < 20)) {
    // Wait to burn in some events
    nixies->clear();
    while(trigCount < 20) {
      char* displayDigits = Nixies::number_to_digits(trigCount, NO_ZERO_PAD);
      nixies->display(displayDigits);
      delay(10);
    }
  }

  if (rotPos1 == LOW) {
    // CLOCK MODE
    DateTime now = rtc.now();

    if(toggleNum > prevToggleNum) {
      uint8_t hour = now.hour();
      uint8_t minute = now.minute();
      uint8_t second = now.second();

      uint8_t toggleFlipped = toggleNum ^ prevToggleNum;

      switch(toggleFlipped) {
        case 16:
          // Increment hour
          hour = (hour + 1) % 24;
          break;
        case 8:
          // Increment 10 minutes
          minute = (minute + 10) % 60;
          break;
        case 4:
          // Increment 1 minute
          minute = (minute + 1) % 60;
          break;
        case 2:
          // Set seconds to zero
          second = 0;
          break;
      }

      // Not using this clock to keep track of days so just always make it 1/1/2000
      DateTime newDateTime = DateTime(2000, 1, 1, hour, minute, second);

      // Set the clock
      rtc.adjust(newDateTime);
    }

    unsigned long int hour_number = 1000000UL * (unsigned long int) now.hour();
    unsigned long int minute_number = 1000UL * (unsigned long int) now.minute();
    unsigned long int second_number = (unsigned long int) now.second();
    unsigned long int time_number = hour_number + minute_number + second_number;
    char* time_digits = Nixies::number_to_digits(time_number, ZERO_PAD);

    time_digits[2] = -1;
    time_digits[5] = -1;
    nixies->display(time_digits);
    delay(10);

    if(controlPanel->switch_state(PUSHBUTTON) == LOW) {
      while(true) {
        if(controlPanel->switch_state(PUSHBUTTON) == HIGH) {
          nixies->clear();
          break;
        }
      }
      delay(200);
      while(true) {
        if(controlPanel->switch_state(ROTARYPOSITION1) != LOW) {
          break;
        }
        if(controlPanel->switch_state(PUSHBUTTON) == LOW) {
          while(true) {
            if(controlPanel->switch_state(PUSHBUTTON) == HIGH) {
              delay(200);
              break;
            }
          }
          break;
        }
      }
    }
    prevToggleNum = toggleNum;
  }
  else if (rotPos2 == LOW) {
    // STREAMING MODE
    trigLedsOn = 1;
    speakerOn = !turboMode;

    nixies->clear();

    uint16_t delayTime;
    if(turboMode) {
      delayTime = 10;
    }
    else {
      delayTime = 1000;
    }

    if(toggleNum == 0) {
      toggleNum = 256;
    }

    uint8_t randByte;

    while(1) {
      randByte = getRandByte(ROTARYPOSITION2);
      if(randByte < (256 - (256 % toggleNum))) {
        break;
      }
    }

    if(controlPanel->switch_state(ROTARYPOSITION2) == LOW) {
      Serial.begin(19200);
      if(toggleNum == 256) {
        Serial.write(randByte);
      }
      else if(toggleNum != 256) {
        Serial.write((randByte % toggleNum) + 1);
      }
      Serial.end();
      delay(delayTime);

      char* displayDigits;

      if(!turboMode) {
        if(toggleNum == 256) {
          displayDigits = Nixies::number_to_digits(randByte, NO_ZERO_PAD);
        }
        else if(toggleNum != 256) {
          displayDigits = Nixies::number_to_digits((randByte % toggleNum) + 1, NO_ZERO_PAD);
        }
        nixies->display(displayDigits);
        delay(delayTime);
      }
    }

    if(controlPanel->switch_state(PUSHBUTTON) == LOW) {
      char all_lit[] = {0, 0, 0, 0, 0, 0, 0, 0};
      char all_off[] = {-1, -1, -1, -1, -1, -1, -1, -1};
      while(1) {
        nixies->display_led(all_lit);
        delay(100);
        nixies->display_led(all_off);
        delay(100);
        if(controlPanel->switch_state(PUSHBUTTON) == HIGH) {
          EEPROM.write(EEPROM_ADDR, ~EEPROM.read(EEPROM_ADDR));
          turboMode = !turboMode;
          break;
        }
      }
    }
  }
  else if(rotPos3 == LOW) {
    // DICE MODE
    trigLedsOn = 0;
    speakerOn = 0;
    nixies->clear();

    if(toggleNum != 0) {
      char* displayDigits = Nixies::number_to_digits(toggleNum, NO_ZERO_PAD);
      nixies->display(displayDigits);
      delay(50);
      nixies->clear();
      delay(50);
    }
    else {
      nixies->clear();
    }

    if((controlPanel->switch_state(PUSHBUTTON) == LOW) && (toggleNum != 0)) {

      uint8_t randByte;
      while(1) {
        trigLedsOn = 1;
        speakerOn = 1;
        randByte = getRandByte(ROTARYPOSITION3);
        if(randByte < (256 - (256 % toggleNum))) {
          trigLedsOn = 0;
          speakerOn = 0;
          break;
        }
      }
      delay(500);
      
      char* displayDigits = Nixies::number_to_digits((randByte % toggleNum) + 1, NO_ZERO_PAD);
      if(controlPanel->switch_state(ROTARYPOSITION3) == LOW) {
        while(1) {
          if(controlPanel->switch_state(ROTARYPOSITION3) != LOW) {
            break;
          }
          nixies->display(displayDigits);
          if(controlPanel->switch_state(PUSHBUTTON) == LOW) {
            break;
          }
        }
        delay(500);
      }
    }
  }
}

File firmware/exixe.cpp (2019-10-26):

#include "exixe.h"
#include <SPI.h>

/*
  SPI command details:
  https://github.com/dekuNukem/exixe/blob/master/technical_details.md

  Project repo:
  https://github.com/dekuNukem/exixe
*/

exixe::exixe(int my_cs)
{
  cs_pin = my_cs;
  memset(spi_buf, 0, EXIXE_SPI_BUF_SIZE);
  pinMode(cs_pin, OUTPUT);
  digitalWrite(cs_pin, HIGH);
  animation_src_digit = 0;
}

void exixe::spi_init()
{
  SPI.begin();
  SPI.beginTransaction(SPISettings(8000000, MSBFIRST, SPI_MODE0));
}

void exixe::spi_write()
{
  digitalWrite(cs_pin, LOW);
  for (int i = 0; i < EXIXE_SPI_BUF_SIZE; ++i)
    SPI.transfer(spi_buf[i]);
  digitalWrite(cs_pin, HIGH);
}

// cap digit between 1 and 10
unsigned char exixe::cap_digit(unsigned char digit)
{
  digit = digit % 10;
  if(digit == 0)
    digit = 10;
  return digit;
}

// cap a float between 0 and 127
unsigned char exixe::cap_float(float temp)
{
  if(temp > 127)
    temp = 127;
  if(temp < 0)
    temp = 0;
  return (unsigned char)temp;
}

// Turn off all digits and LED
void exixe::clear()
{
  memset(spi_buf, 0x80, EXIXE_SPI_BUF_SIZE);
  spi_buf[0] = EXIXE_SPI_HEADER;
  spi_write();
}

void exixe::show_digit(unsigned char digit, unsigned char brightness, unsigned char overdrive)
{
  // cap brightness to 127
  brightness &= 0x7f;
  digit = cap_digit(digit);

  memset(spi_buf, 0, EXIXE_SPI_BUF_SIZE); // clear SPI buffer
  memset(spi_buf, 0x80, EXIXE_SPI_BUF_SIZE - 5); // set EN bit to 1 for all digits
  spi_buf[0] = overdrive ? EXIXE_SPI_HEADER_OD : EXIXE_SPI_HEADER; // first byte, header
  spi_buf[digit] = 0x80 | brightness; // set digit brightness

  animation_src_digit = digit;
  spi_write();
}

void exixe::set_led(unsigned char red, unsigned char green, unsigned char blue)
{
  // cap brightness to 127
  red &= 0x7f;
  green &= 0x7f;
  blue &= 0x7f;

  memset(spi_buf, 0, EXIXE_SPI_BUF_SIZE - 3); // clear SPI buffer
  spi_buf[0] = EXIXE_SPI_HEADER;
  spi_buf[13] = 0x80 | red; // set LED colors
  spi_buf[14] = 0x80 | green;
  spi_buf[15] = 0x80 | blue;

  spi_write();
}

void exixe::set_dots(unsigned char left_brightness, unsigned char right_brightness)
{
  // cap brightness to 127
  left_brightness &= 0x7f;
  right_brightness &= 0x7f;

  memset(spi_buf, 0, EXIXE_SPI_BUF_SIZE);
  spi_buf[0] = EXIXE_SPI_HEADER;
  spi_buf[11] = 0x80 | left_brightness;
  spi_buf[12] = 0x80 | right_brightness;

  spi_write();
}

void exixe::crossfade_init(unsigned char digit, unsigned int duration_frames, unsigned char brightness, unsigned char overdrive)
{
  animation_dest_digit = cap_digit(digit);
  animation_start_frame = millis() / EXIXE_ANIMATION_FRAME_DURATION_MS;
  animation_duration = duration_frames;
  animation_brightness = brightness & 0x7f;
  animation_overdrive = overdrive;
  animation_step = (float)animation_brightness / (float)animation_duration;
}

unsigned char exixe::crossfade_run()
{
  unsigned long current_frame = (millis() / EXIXE_ANIMATION_FRAME_DURATION_MS) - animation_start_frame;
  
  if(current_frame > animation_duration)
  {
    animation_src_digit = animation_dest_digit;
    return EXIXE_ANIMATION_FINISHED;
  }

  memset(spi_buf, 0, EXIXE_SPI_BUF_SIZE);
  memset(spi_buf, 0x80, EXIXE_SPI_BUF_SIZE - 5);
  spi_buf[0] = animation_overdrive ? EXIXE_SPI_HEADER_OD : EXIXE_SPI_HEADER;
  
  unsigned char temp = cap_float(animation_step * (float)current_frame);
  spi_buf[animation_src_digit] = 0x80 | (animation_brightness - temp);
  spi_buf[animation_dest_digit] = 0x80 | temp;
  spi_write();

  return EXIXE_ANIMATION_IN_PROGRESS;
}

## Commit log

2019-09-01 added stuff for nixies/switches---still need to remove bias from dice mode
2019-09-01 dice de-biased
2019-09-05 off button for clock display; dice mode bug fix
2019-09-07 add pcb files and rename firmware
    [nixie_display_board.kicad_pcb, nixie_display_board.sch, nixie_display_board.step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]
2019-09-07 update logic board for compatibility with front panel board
    [rad_dice_logic_board.kicad_pcb, rad_dice_logic_board.sch]
2019-09-15 updated for control panel pcb
2019-09-17 tweak nixie led mode color
2019-09-22 fix gnd/5v bug and add 2 gpio pins
    [rad_dice_logic_board.kicad_pcb, rad_dice_logic_board.sch]
2019-10-03 change format of parts list; add parts directory and associated files
    [enclosure_half_lg.stl, enclosure_half_sm.stl, front_panel.dxf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]
2019-10-24 fix small issues so code will compile
    [firmware.ino]
2019-10-26 correct order of nixie tubes and increase spi freq
    [exixe.cpp, firmware.ino]
2019-11-07 add wiring schematic
2019-11-12 add image of device
2019-11-12 add wiring diagram to readme
2019-11-18 attempt to add extra de-biasing step
2019-11-20 debug previous commit related to extra de-bias step
2019-11-25 add table for standoff sizes
2019-12-03 documentation progress
    [parts_list.csv]
2019-12-04 add nixie holder and update parts list to include sample holder
    [enclosure_half_lg.stl, enclosure_half_sm.stl, front_panel.dxf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]
2019-12-04 fix parts list
    [parts_list.csv]
2019-12-05 add remainder of parts files
    [enclosure_big_half.stl, enclosure_small_half.stl, front_panel.dxf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]
2019-12-08 revert firmware to von neumann methode approach
    [firmware.ino]
2019-12-20 add extra de-biasing
2019-12-21 update README with test results and add sample data files
